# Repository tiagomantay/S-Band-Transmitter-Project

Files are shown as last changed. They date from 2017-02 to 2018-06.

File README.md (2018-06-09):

# S-Band-Transmitter-Project

The project contains the validation PCBs for each transmitter component, developed with KICAD software.

See the file "S-Band Transmitter.pdf" for full documentation.

What are on this repository:

+ KICAD PCBs layouts and schematics

+ 3D preview of each PCB (3D folder)

+ GERBER files

+ Full documentation with simulations and calculations

+ Low cost project with COTS(Commercial off-the-shelf) components

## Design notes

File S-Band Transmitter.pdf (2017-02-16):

UNIVERSIDADE FEDERAL DE SANTA MARIA CENTRO DE TECNOLOGIA
CURSO DE ENGENHARIA DE COMPUTAÇÃO

PROJETO DE UM TRANSMISSOR HOMÓDINO EM BANDA S PARA APLICAÇÕES EM NANOSSATÉLITES

TRABALHO DE GRADUAÇÃO

Tiago Mantay

Santa Maria, RS, Brasil

2016

## PROJETO DE UM TRANSMISSOR HOMÓDINO EM BANDA S PARA APLICAÇÕES EM NANOSSATÉLITES

Tiago Mantay

### Trabalho de Graduação apresentado ao Curso de Engenharia da Computação da Universidade Federal de Santa Maria (UFSM, RS), como requisito parcial para a obtenção do grau de

Bacharel em Engenheiro de Computação

Orientador: Prof. Dr. Renato Machado

Santa Maria, RS, Brasil

2016

Universidade Federal de Santa Maria Centro de Tecnologia
Curso de Engenharia Elétrica

A Comissão Examinadora, abaixo assinada, aprova o Trabalho de Conclusão de Curso

## PROJETO DE UM TRANSMISSOR HOMÓDINO EM BANDA S PARA APLICAÇÕES EM NANOSSATÉLITES

### elaborado por

Tiago Mantay

### Como requisito parcial para a obtenção do grau de

Bacharel em Engenharia Elétrica

COMISSÃO EXAMINADORA:

______________________________ Renato Machado, Dr.
(Orientador)

________________________________ Prof. Marcelo Zanetti, Dr. (UFSM)

___________________________________ Vinícius Ludwig Barbosa, Eng. (UFSM)

Santa Maria, 16 de dezembro de 2016

AGRADECIMENTOS

Agradeço primeiramente a minha família, especialmente meus pais, Elmar e

Juraci, e minha namorada Katiane, que sempre me apoiaram em todos os momentos

pacientemente.

Gostaria de agradecer aos colegas do grupo de pesquisa e amigos Cristiano Santos,

Juliano Rafael Andrade e Vinícius Barbosa pelos momentos compartilhados e troca de

experiências, colaborando de diversas formas.

Agradeço especialmente ao meu orientador, Renato Machado, pela confiança

depositada aceitando a orientação deste trabalho e por toda ajuda e conhecimentos

repassados.

RESUMO

Trabalho de Conclusão de Graduação

Curso de Engenharia de Computação

Universidade Federal de Santa Maria

PROJETO DE TRANSMISSOR HOMÓDINO EM BANDA S PARA APLICAÇÕES EM NANOSSATÉLITES

AUTOR: TIAGO MANTAY

ORIENTADOR: RENATO MACHADO

Local de Defesa e Data: Santa Maria, 16 de Dezembro de 2016

Atualmente, o estudo das tecnologias voltadas para aplicações espaciais tem

crescido consideravelmente. Este fato se deve a redução da complexidade, dos custos e

do tempo envolvido no desenvolvimento de projetos. Satélites de pequeno porte vêm

sendo utilizados para a validação de experimentos científicos e tecnológicos. O sistema

de comunicação é um dos mais críticos componentes de um nanossatélite. Este trabalho

apresenta um protótipo de um front-end de transmissor Homódino de dois canais que

opera em banda S, com componentes comercializados irrestritamente. Por fim, foram

desenvolvidas placas de circuito impresso para validação individual dos componentes que

juntas formam um canal completo do transmissor.

ABSTRACT

Undergradute Final Work

Graduation on Computing Engineer

Federal University of Santa Maria

Technology Center

DESIGNING OF A S-BAND HOMODINE TRANSMITER FOR

NANO-SATELLITES APPLICATIONS

AUTHOR: TIAGO MANTAY

ADVISOR: RENATO MACHADO
Place and Data of Presentation: Santa Maria, December 15th, 2016

Recently, the study of technologies for space applications has grown considerably.

This is due to the reduction of the complexity, the costs and the time involved in the

development of projects. The applicability of small satellites has increased a lot lately,

comes to simplify the validation of scientific and technological experiments. The

communication system is one of the main components of a nanosatellite. This work

presents a prototype of a two-channel Homodine transmitter front-end wich operate in S-

band, with unrestricted commercially available components. Printed circuit boards were

developed for individual component validation, together form a complete transmitter

channel.

LISTA DE ABREVITATURAS E SIGLAS

AEB – Agência Espacial Brasileira

BER – Bit Error Rate (Taxa de erro de bit)

BPSK – Binary Phase Shift Keying (Modulação por Chaveamento de Fase)

CI – Circuito Integrado

FPGA – Field Programmable Gate Array

IF – Frequência Intermediária

INPE - Instituto Nacional de Pesquisas Espaciais

ITA – Instituto Tecnológico de Aeronáutica LEO – Low Earth Orbit (Órbita Terrestre Baixa)

LO – Local Oscilator (Oscilador Local)

MCT – Ministério da Ciência e Tecnologia

PA – Power Amplifier (Amplificador de Potência)

PCI – Placa de Circuito Impresso

RF – Rádiofrequência

SNR – Razão sinal-ruído

VCO – Voltage Control Oscilator (Oscilador controlado por tensão)

UFSM – Universidade Federal de Santa Maria

UFRGS – Universidade Federal do Rio Grande do Sul

LISTA DE FIGURAS

LISTA DE TABELAS

Tabela 6.2: Parâmetros iniciais servindo de base para a escolha dos componentes ....... 37

Tabela 6.5: Representação dos valores de ganhos e figura de ruído em valores lineares e

SUMÁRIO

### 1. INTRODUÇÃO

O setor aeroespacial vem recebendo grandes investimentos por parte do governo

brasileiro, priorizando projetos de pesquisa e desenvolvimento tecnológico que vêm

sendo desenvolvidos pela academia, institutos de pesquisa e através da parceria entre

estes. Uma das áreas considerada como estratégica e prioritária para o governo brasileiro

é a área de satélites, a qual é imprescindível para diversos segmentos como o de

monitoramento ambiental, telecomunicações e defesa.

A academia tem desenvolvido diversos trabalhos envolvendo nanossatélites, os

quais são uma boa opção para a realização de testes e validação de conceitos por

oferecerem menor custo e complexidade do que os satélites de maior porte. Em geral,

podem ser projetados para realizar missões para telemetria de dados coletados por

dispositivos como sensores de temperatura, magnetômetro, entre outras aplicações.

Cientes do potencial estratégico, o Instituto Nacional de Pesquisas Espaciais (INPE) em

parceria com a Agência Espacial Brasileira (AEB) vêm desenvolvendo programas para

construção de satélites de pequeno porte no Brasil desde 2003.

A comunicação do satélite com as estações terrenas é viabilizada pelo subsistema

de telemetria e telecomando, responsável por enviar dados da carga útil e dos sistemas de

bordo e receber comandos. Na maioria dos projetos nacionais de satélites de pequeno

porte foram utilizados transceptores de empresas estrangeiras, adicionando custos

consideráveis ao projeto.

### 1.1 Objetivos

O objetivo deste trabalho é desenvolver um protótipo de front-end de transmissor

que possa ser utilizado em nanossatélites. Mais precisamente, o trabalho propõe um

protótipo de baixo custo de um circuito transmissor que opere em banda S, com

arquitetura própria, utilizando componentes Off-The-Shelf, para aplicações em

nanossatélites que operam em órbita baixa.

O desafio do projeto está em garantir que o transmissor seja robusto e confiável e

que o receptor detecte e decodifique o sinal de telemetria recebido. As características de um link espacial aumentam a complexidade dos problemas, pois uma vez que o satélite é

lançado não há como realizar modificações ou manutenções. O canal de comunicação

também é um desafio a ser considerado, pois além de distância de transmissão (maior do

que 600km), existem diversas variáveis que podem corromper a informação.

### 1.2 Organização do trabalho

O trabalho incialmente apresenta um breve histórico dos nanossatélites e uma

revisão bibliográfica sobre características da comunicação digital, do canal de

comunicação e eletrônica de alta frequência. A revisão também inclui um estudo sobre a

arquitetura homódina e aspectos relevantes sobre circuitos transmissores.

No Capítulo 3, apresenta-se o projeto do transmissor, que enfatiza a arquitetura e

os componentes utilizados no projeto, as justificativas para as escolhas de padrões

utilizados, além de cálculos necessários para o funcionamento do circuito. Nos Capítulos

4 e 5, discutem-se os layouts das placas para os componentes do circuito e também uma

simulação do desvanecimento do sinal no canal de comunicação.

Por fim, o Capítulo 7, a conclusão, discute as metodologias utilizadas, as

atividades realizadas, as melhorias que poderão ser implementadas em trabalhos futuros

e a aplicação deste trabalho no contexto de nanossatélites.

### 2. NANO-SATÉLITES

Nano-satélites são satélites artificiais miniaturizados, que pesam entre 1 e 10 Kg

e projetados para aplicações em órbita baixa (LEO – Low Earth Orbit). Tipicamente, possuem dimensões de 10 cm³
. Em seu design, na maioria dos casos, são utilizados

componentes off-the-shelf e possuem custo muito inferior a satélites de médio e grande

porte.

O Cubesat, modelo extensivamente utilizado de nanossatélite, é originário de

pesquisadores das Universidades Estadual Politécnica da Califórnia (Cal Poly) e

Stanford, que por volta dos anos 2000 desenvolveram o padrão, juntamente com

especificações necessárias para promover projetos nesse âmbito. Os Cubesats podem

pesar até 1,33Kg

Até 2013, os nanossatélites lançados eram majoritariamente universitários. A

partir daí, pode-se observar um aumento significativo de projetos comerciais e amadores.

A Figura 2.1 apresenta uma ilustração de uma constelação de nanossatélites em órbita

terrestre (THE CUBESAT PROGRAM, 2014).

Figura 2.1 - Ilustração de uma constelação de nanossatélites em órbita terrestre.

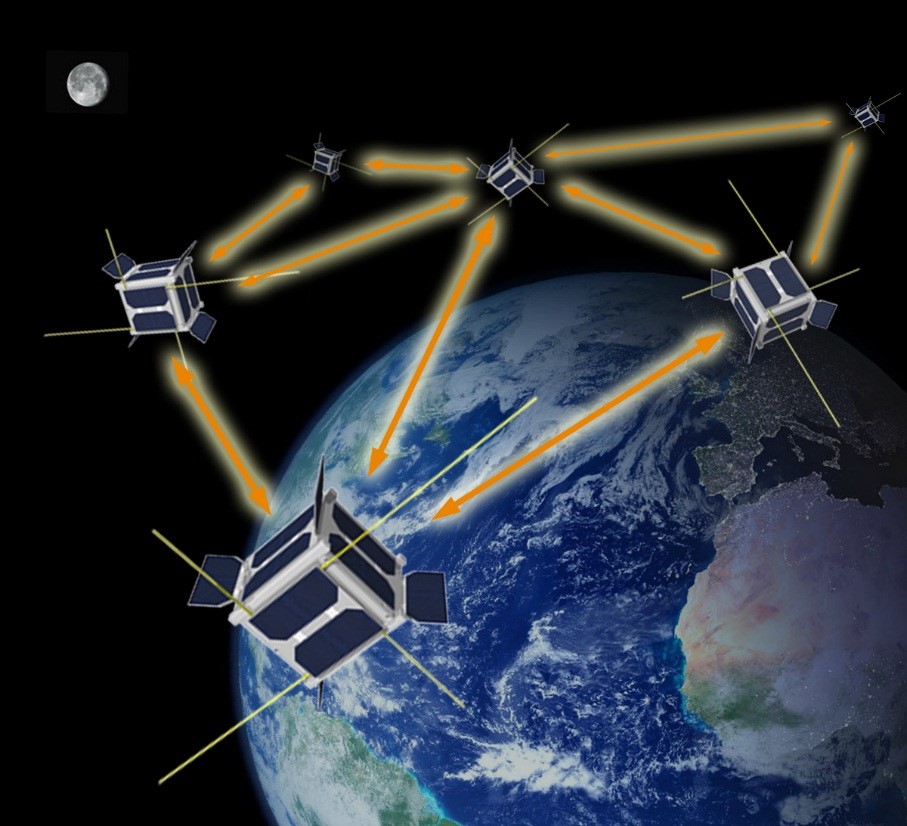
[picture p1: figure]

Fonte: (BENTUM, 2014)

### 2.1 Introdução

Graças aos recentes avanços tecnológicos e do conhecimento acumulado pela

comunidade científica, o número de nano-satélites lançados ao espaço tem aumentado

significativamente. Além disso, o custo de lançamento do satélite, que representa grande

parte do investimento do projeto, tem caído gradualmente à medida que novos lançadores

são construídos e novas tecnologias são empregadas.

As vantagens oferecidas quando em comparação com satélites maiores são muito

expressivas, permitindo que projetos de nível universitário, sem grandes investimentos,

sejam executados com sucesso. Atualmente é possível desenvolver um satélite de

pequeno porte exclusivamente com componentes comerciais do tipo off-shelf.

Além de possuírem a capacidade de realizar tarefas que alguns anos atrás eram

exclusivas de satélites de grande porte, o uso de nanossatélites tem facilitado muito a

realização de todo tipo de experimentos científicos no ambiente espacial. No entanto,

cabe ressaltar que o tempo de vida médio de um nanossatélite em órbita é de 2 anos.

Um sistema de comunicação via satélite necessita no mínimo de um satélite

transmissor e uma estação rádio base para receber as informações do espaço. Para que

haja confiabilidade no tráfego dos sinais, faz-se necessário a implementação de um

protocolo robusto. Esse trabalho avalia dois protocolos clássicos e elege um deles para

conceber o transmissor do projeto. Maiores detalhes são apresentados no Capítulo 3.

A estrutura mecânica utilizada em satélites de pequeno porte é modular, deste

modo a integração dos sistemas é facilitada (BENTUM, 2014).

A Figura 2.2 apresenta um modelo de estrutura mecânica dos Cubesats.

Figura 2.2 – Estruturas padronizadas de Cubesats

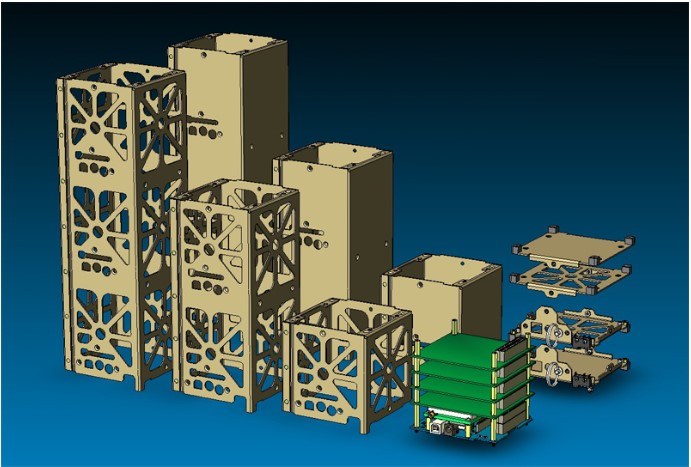
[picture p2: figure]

Fonte: (Clyde-Space, 2009). A ilustração apresenta 3 diferentes modelos de Cubesats. Da esquerda para a

direita, padrão 3U, 2U e 1U.

### 2.2 Missões brasileiras de satélites de pequeno porte

2.2.1 AESP-14

O AESP-14 foi um Cubesat U1, lançado em fevereiro de 2015, declarado

inoperante dias após seu lançamento. Seu objetivo era realizar um estudo da dinâmica da

Atmosfera ionizada. Este projeto foi executado por estudantes de Graduação do ITA e

de Pós-Graduação INPE que fizeram um trabalho de engenharia reversa do satélite

NANOSATC-BR1. O projeto foi executado em Campos do Jordão - São Paulo.

O Cubesat AESP-14 pode ser visto na Figura 2.3 e na Figura 2.4 o transmissor do

desenvolvido no projeto por alunos do ITA e do INPE (INPE, 2015).

Figura 2.3 – Nano satélite AESP-14

Fonte: (INPE, 2015)

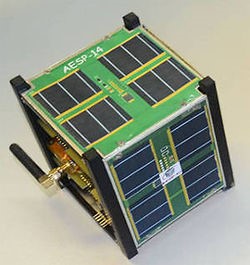
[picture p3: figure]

Figura 2.4 – Transmissor do nano satélite AESP-14

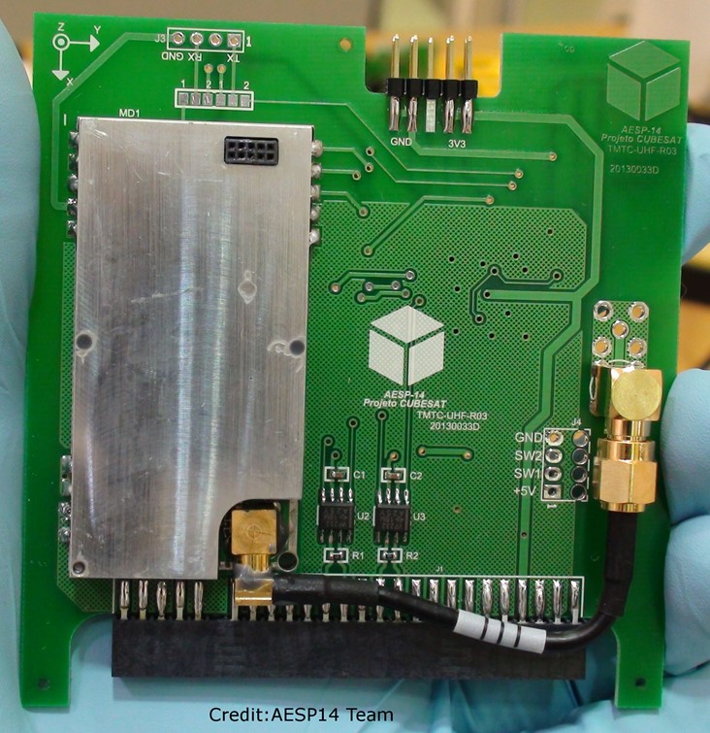
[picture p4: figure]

Fonte: (INPE, 2015)

### 2.2.2 BR-1

Lançado em 19 de julho de 2014, o Cubesat BR-1 foi desenvolvido por

pesquisadores do INPE e da UFSM com dois objetivos, um cientifico e outro tecnológico.

A Missão Tecnológica do NANOSATC-BR1 foi a realização de testes de CIs

tolerantes à radiação ionizante, produzidos por pesquisadores da SMDH em parceria com

a UFSM. A missão científica foi, principalmente, a coleta de dados referentes ao Campo

Magnético Terrestre, na região da América do Sul onde há anomalias no campo

magnético da terra (INPE, 2014).

Segundo Otávio Durão, coordenador de engenharia e tecnologia espacial de

projetos de nanossatélites do INPE, o custo total do projeto foi próximo de R$ 800 mil.

Em 24 de junho de 2014, 5 dias após seu lançamento, as estações terrenas do INPE

em Santa Maria e São José dos Campos, captaram sinais enviados do Cubesat,

comprovando o sucesso do projeto (AEB, 2015). A Figura 2.5 apresenta o Cubesat BR1.

Figura 2.5 – Nano-Satélite BR1. Detalhes da bancada de teste e da carga útil lançada na missão.

Fonte: (INPE, 2015)

### 3. SISTEMAS DE COMUNICAÇÃO DIGITAL

Os princípios da comunicação digital remetem a Claude Shannon, em seu famoso

livro intitulado A mathematical theory of communication (A teoria matemática da

comunicação), publicado em 1949 em coautoria com Warren Weaver. Neste livro,

lançado após o artigo de mesmo nome, são sistematizados conceitos fundamentais para o

entendimento da eficiência em sistemas de comunicação que possibilitaram grandes

avanços na área (KINCHIN, 1957).

Um sistema de comunicação tem como propósito transportar uma mensagem de

um ponto no espaço a outro. Se o sistema for digital, a mensagem será composta de dados

(bits). Os principais componentes de um sistema de comunicação são: a fonte de

informação, o transmissor, o receptor e o destino (LATHI, 1998).

O diagrama da Figura 3.1 apresenta os componentes de um sistema de

comunicação digital.

Figura 3.1 – Diagrama de um sistema de transmissão de dados

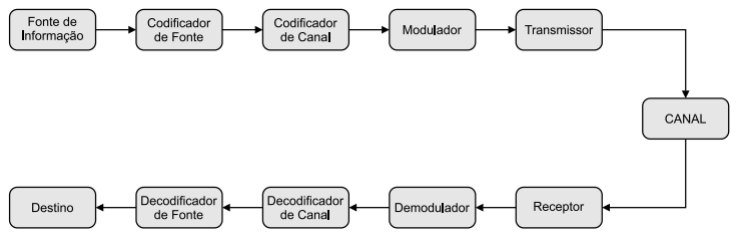
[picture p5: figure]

Fonte: (Autoria própria)

- Fonte de Informação – onde a informação é gerada
- Codificador de Fonte – retira o excesso de redundância proveniente da

fonte de informação;

- Codificador de Canal – responsável por codificar os sinais de informação

objetivando a redução da BER durante a transmissão;

- Modulador – realiza o processo de conversão digital/analógico, necessário

para inserir informações em um sinal analógico;

- Transmissor – componente responsável pela manipulação e o envio do

sinal através do canal;

- Canal – meio físico por onde o sinal é propagado, adicionando sempre

ruídos ao sinal original;

- Receptor – componente responsável por receber e tratar o sinal que se

propagou através do canal;

Receptores, transmissores e transceptores, geralmente são responsáveis por

acumular outras funções como modulação/demodulação, codificação/decodificação,

amplificação, filtragem, verificação de erros, entre outros procedimentos (LATHI, 1998).

### 3.1 Transmissão de dados

Os sistemas de comunicação podem operar de diferentes formas e empregar

diferentes técnicas. Basicamente, pode-se classificar um sistema de comunicação

considerando o fluxo de informações do transmissor para o receptor. Os esquemas de

transmissão podem ser classificados de acordo com a habilidade dos agentes transmitirem

e receberem informações ao longo do tempo, dessa forma existem três modalidades:

Simplex, Half-duplex e Full-duplex.

3.1.1 Transmissão Simplex

Este esquema é caracterizado pela existência de um agente transmissor e um

agente receptor. O modelo Simplex é largamente empregado por estações de rádio,

sistema GPS e satélites.

3.1.2 Transmissão Half-Duplex

O esquema Half-duplex permite que ambos agentes transmitam e recebam

informações, porém somente um agente pode transmitir por vez. Rádios amadores

utilizam o esquema Half-duplex para comunicarem entre si.

3.1.3 Transmissão Full-duplex

Sistemas de comunicação onde ambos agentes podem enviar e receber dados

simultaneamente são chamados de Full-duplex. A telefonia é um exemplo de esquema

Full-duplex, onde os dois agentes de comunicação podem receber e enviar dados

simultaneamente (LATHI, 1998).

A Figura 3.2 apresenta uma ilustração dos esquemas Simplex, Half-duplex e Full-

duplex.

Figura 3.2: Esquemas de transmissão

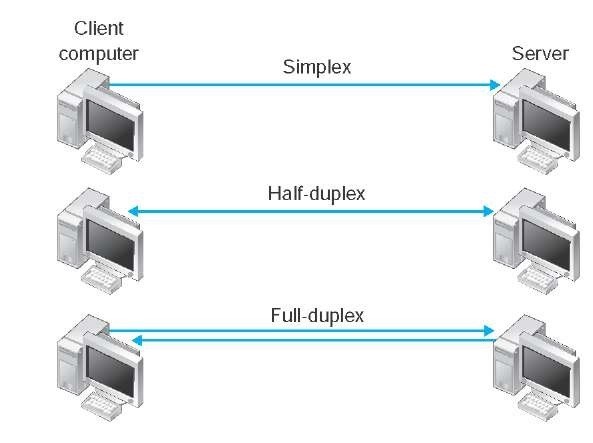
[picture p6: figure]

Fonte: (Autoria própria). Modelo de esquemas de transmissão.

### 3.2 Características de um sistema de comunicação wireless

Existem sistemas de comunicação de todos os níveis, local, regional, nacional e

global. Cada sistema deve possuir as características que a sua aplicação demande. A

distância de transmissão, a qualidade, a confiabilidade e a velocidade dos dados são

fatores de extrema importância na construção de um sistema de comunicação.

O conhecimento dos efeitos gerados pelo canal de comunicação utilizado pelo

sistema é de vital importância no projeto. O ruído acrescentado pelo canal tem grande

influência na arquitetura e nas tecnologias empregadas no sistema de comunicação, para que o mesmo seja eficiente e confiável. Atualmente a transmissão sem fio (wireless) é

largamente utilizada pelas facilidades oferecidas, porém, a vantagem de não necessitar

meios físicos artificiais traz como desvantagem a enorme quantidade de efeitos

indesejados ao sinal transmitido.

De forma geral, as características mais importantes que definem um sistema de

comunicação sem fio são a taxa de dados, a largura de banda, a frequência de transmissão

e a SNR desejada (RAPPAPORT, 2011).

3.2.1 Taxa de dados

Uma das características mais importantes em um sistema de comunicação é a

velocidade de transmissão, ou seja, a quantidade de dados enviados por unidade de tempo.

Essa medida pode ser chamada de taxa de dados ou bit rate, e é usualmente expressa em

bits por segundo ou símbolos por segundo.
É apropriado definir, nas primeiras etapas do projeto, a taxa de dados mínima

requerida, para então dimensionar e definir as demais características do sistema.

Geralmente deseja-se a maior taxa de transmissão possível dentro dos limites de execução

do projeto.

A velocidade da transmissão está intimamente associada a outros fatores como a

qualidade da transmissão, a modulação empregada, a redundância e, principalmente, o canal de comunicação. É necessário garantir baixos índices de BER, e a maior SNR

possível no receptor, para evitar retransmissões de dados.

3.2.2 Largura de banda

A largura de banda de um sistema é a faixa de frequência que será utilizada para

o envio das informações. Este parâmetro tem relação direta com a capacidade de

transmissão. Para um canal ideal (sem adição de ruído), quanto maior a largura de banda,

maior será a capacidade do canal, segundo a Equação 3.1.

C = 2B | (3.1)

Em que C é a capacidade do canal e B a largura de banda do sinal (Hz) no caso do

sistema utilizar 2 níveis de tensão, ou seja, 1 símbolo por bit (NASCIMENTO, 2007).

A Equação que apresenta a capacidade do canal para sinais com N níveis, é

apresentada a seguir:

C = 2B log2 N | (3.2)

3.2.3 SNR

A relação sinal-ruído estabelece uma importante relação entre a potência do sinal

e a potência do ruído no receptor. Esta relação é logarítmica e expressa em dB pela

Equação abaixo.

S
N

= 10 log potência do sinal potência de ruído

(3.3)

Quanto menor a diferença entre as potências do sinal transmitido e do ruído, maior

será a probabilidade que ocorra um erro de bit. De modo que a potência do sinal recebido

deve ser suficientemente maior que a potência de ruído para que seja possível decodificar

a informação.

3.2.4 Erro de bit

A taxa de erro de bit ou BER (Bit Error Rate) é a relação direta entre a quantidade

de bits transmitidos e a quantidade de bits decodificados erroneamente e constitui um

parâmetro fundamental para avaliar-se a qualidade de transmissão. Quanto maior a BER

de um sistema, menor será a taxa efetiva de transmissão de bits, pois mais bits terão de

ser retransmitidos ou serão perdidos.

3.2.5 Frequência de transmissão

Em sistemas de transmissão sem fio, surge a necessidade de utilizar uma

frequência, denominada portadora, que utilizada para “carregar” a informação

transportada pelo canal. O espectro de frequências utilizado deve estar em conformidade

com a legislação (no Brasil regida pela ANATEL). Além disso, a portadora terá grande influência sobre o projeto do sistema de comunicação no que se refere ao efeito do canal,

projeto das antenas e do receptor/transmissor.

A frequência portadora modula o sinal através do processo chamado

upconversion, e será recuperado no receptor através do processo de downconversion

(NASCIMENTO, 2007).

Este processo é resultado da operação chamada de convolução dos dois sinais,

conforme ilustra a Figura 3.3.

Figura 3.3 – Processo de upconversion

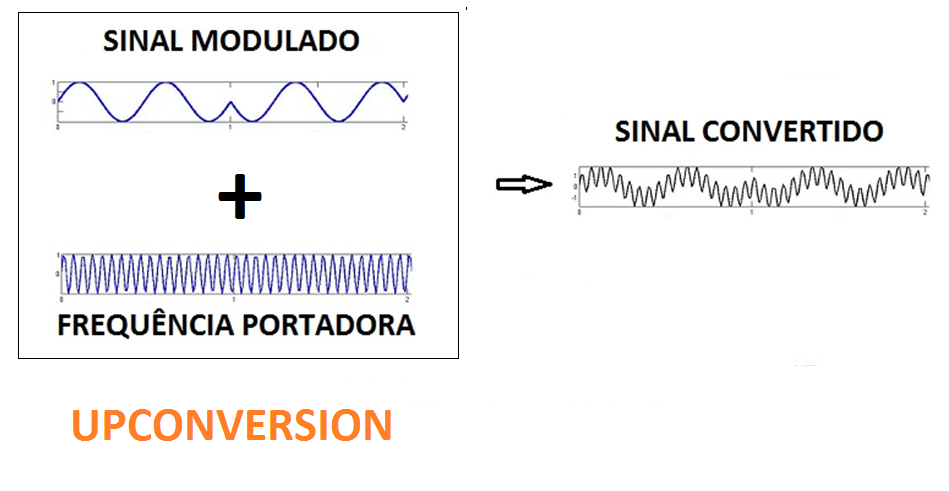
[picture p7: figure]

Fonte: (Autoria própria). Processo de conversão de um sinal modulado para a frequência de transmissão,

no processo chamado upconversion.

### 3.3 O canal de comunicação

Existem diversos meios físicos para conduzir o fluxo de informações do

transmissor até o receptor, guiados ou não-guiados. Esses meios são chamados de canais

de comunicação. O sinal pode trafegar por meio de condutores sólidos, líquidos ou

gasosos. Os meios mais utilizados atualmente são sólidos (cabos) e gasosos (ar).

Para transmissões sem fio, o canal de comunicação é um dos primeiros fatores

limitantes a ser levado em consideração quando se está projetando sistemas de

comunicação pelo fato de, geralmente, causarem maior parte das atenuações e

interferências no sinal em questão. (TANENBAUM, 1996)

3.3.1 Modelagem do canal de Comunicação

A Equação de Friis simplificada, (Equação 3.4) nos permite realizar uma

aproximação do cálculo da perda de potência no espaço livre, utilizando como parâmetros

os ganhos das antenas, a potência de transmissão, a distância entre transmissor e receptor

e comprimento de onda do sinal (LATHI, 1998).

Pr = Pt ∗ (

λ
4πd)

2
∗ Gt ∗ Gr | (3.4)

Sendo :

Pr a Potência recebida em watts
Pt a Potência transmitida em watts λ o Comprimento de onda em metros Gt o Ganho da antena transmissora Gr o Ganho da antena receptora

O comprimento de onda (λ) pode ser calculado a partir da frequência (F), em que v = 300.000.000 m/s. (RAPPAPORT, 2011)

λ =

v
F

(3.5)

### 3.4 Modulação digital

A modulação é o processo que permite adicionar informação a um sinal através

da variação de frequência (FM), amplitude (AM) ou fase (PM) do sinal. Esse processo

pode ser executado na forma analógica ou digital.

O circuito analógico requer o projeto individual para cada tipo de modulador, ou

seja, diferentes componentes deverão ser especificados para que o circuito atenda a

demanda requisitada. Por outro lado, a modulação digital é muito mais versátil,

permitindo a programação e implementação de diversos esquemas de modulação com o

mesmo circuito físico. Para fins práticos, independentemente do processo de modulação considerado, o sinal resultante desse processo é analógico (HAYKIN, 2004).

3.4.1 BPSK

A modulação BPSK (do inglês, Binary Phase Shift Keying) é uma modulação que

emprega o sistema de deslocamento de fase e possui a capacidade de transmitir 1 bit por

símbolo. Sendo considerado um esquema robusto, além de facilitar o tratamento de erros.

Além de ser um esquema muito robusto, ou seja, tolerante a um nível alto de ruído,

o esquema BPSK também é de fácil implementação (RAPPAPORT, 2011).

### 3.5 Protocolos de comunicação

Para garantir a funcionalidade e eficiência no processo de comunicação é

necessário a definir qual padrão será utilizado para transmissão/recepção do sinal. Os

protocolos devem ser escolhidos de forma que o formato dos dados facilite a

implementação das diversas funcionalidades do sistema.

Quando se transmite dados digitais, estes devem seguir uma métrica, devem ser

divididos e quantificados. A divisão dos dados é implementada através de pacotes. Cada

pacote carrega, além dos bits de dados a serem enviados, bits de controle para detecção e

correção de erros, bits de endereçamento, entre outras funções. Há protocolos que são

mais utilizados que outros, normalmente por terem sido mais testados e aperfeiçoados ao

longo do tempo.

Em aplicações militares ou que requeiram um nível maior de segurança ou

customização, pode vir a ser necessário implementar um protocolo próprio para o sistema

idealizado. (LATHI, 1998)

3.5.1 Modelo OSI

O modelo OSI (Interconexão de Sistemas Abertos, do inglês: Open Systems

Interconnection) foi desenvolvido a fim de criar um padrão de protocolo de comunicação

entre sistemas, garantindo a compatibilidade em redes de dados digitais. Ao total são 7

camadas: Física, enlace, rede, transporte, sessão, apresentação e aplicação. Em muitos

sistemas não há necessidade de implementação de todas as camadas do modelo OSI

(TANENBAUM, 1996).

A Figura 3.4 descreve as camadas da estrutura do modelo OSI

Figura 3.4: Camadas do modelo OSI

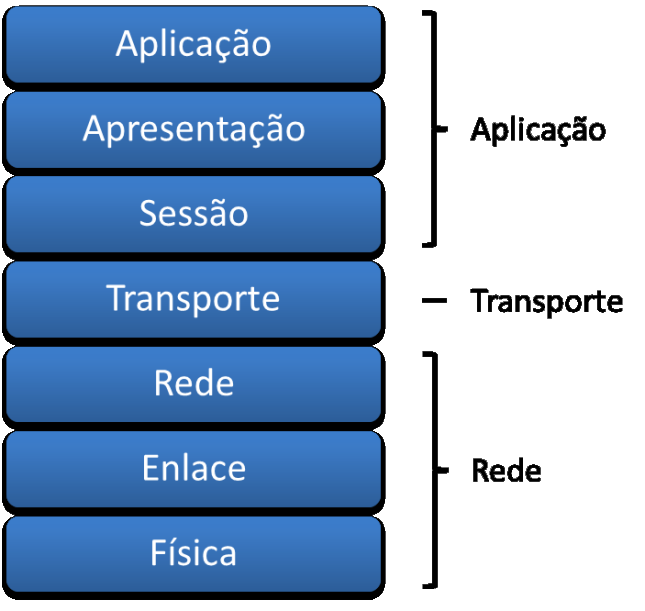
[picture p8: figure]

,

Fonte: (Autoria própria)

3.5.2 Protocolo AX.25

O objetivo deste protocolo é assegurar a compatibilidade entre estações de

transmissão e recepção, permitindo a usuários um alto nível de integração entre as partes

de um sistema de comunicação. Um padrão amplamente utilizado traz consigo muitos

benefícios, principalmente pelo fato de ser continuamente testado e melhorado.

O AX.25 foi derivado do protocolo X.25 e foi desenvolvido por operadores de

radioamador. Os avanços no protocolo X.25 foram necessários para permitir a inclusão

das opções de endereçamento e outras características da transmissão via rádio.

A ampla compatibilidade do AX.25 com milhares de rádio amadores do mundo

inteiro é um dos motivos que justificam a aderência por diversos projetistas, incluindo

nano satélites. O diagrama das camadas OSI do protocolo AX.25 pode ser visualizado na

Figura 3.5 apresentando uma estrutura com 3 camadas, implementadas na estação de

controle, no satélite e nos terminais (ADDAIM, 2010).

Figura 3.5 – Camadas da comunicação via satélite

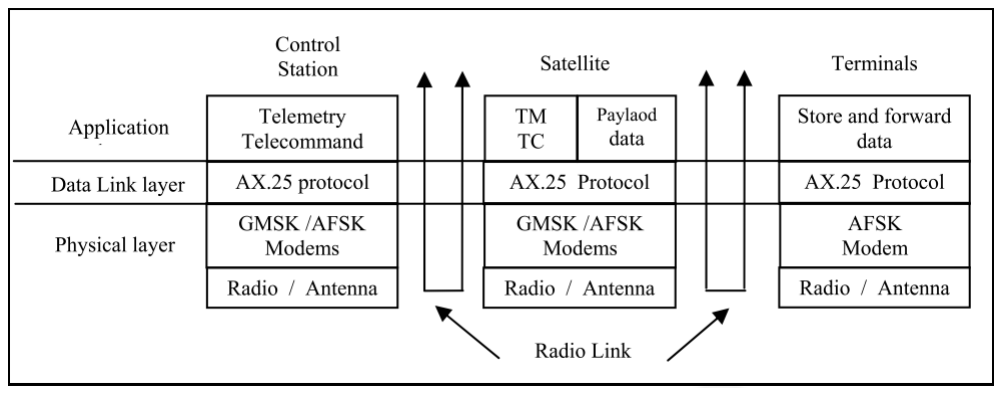
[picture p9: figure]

Fonte: (ADDAIM, 2010)

Este protocolo provê o serviço de padronização das comunicações sem necessitar

camadas superiores do modelo OSI. Além de ser funcional na operação com circuitos de

RF parcialmente prejudicados, o protocolo possui inúmeros benefícios e otimizações que

foram sendo incorporados ao longo dos anos.

O AX.25 oferece uma interface que prevê correções e detecções de erros,

retransmissão de pacotes, opções de controle e possibilidades de encapsulamento via

pacotes IP ou UDP. A Figura 3.6 ilustra um pacote de que segue o protocolo AX.25.

(Tucson Amateur Packet Radio Corporation, 1998).

Figura 3.6: Pacote de informação do protocolo AX.25

Fonte: (Tucson Amateur Packet Radio Corporation, 1998).

Nanossatélites que utilizam o protocolo AX.25 possibilitam que usuários de

radioamador possam receber e decodificar os sinais advindos do espaço, auxiliando os

pesquisadores na confirmação do funcionamento dos dados obtidos pela carga útil dos

satélites.

### 4. LINHAS DE TRANSMISSÃO E MICROONDAS

Em sinais com componentes de alta frequência (microondas), elementos de

circuitos como resistores, capacitores e indutores apresentam um comportamento muito

diferente de quando se trabalha com baixas frequências. Este fenômeno ocorre porque

existe, para altas frequências, uma maior expressão do efeito skin e das perdas por

radiação nesses componentes e nas PCIs.

Para sinais com frequências superiores a 300 MHz, o comprimento de onda do

sinal passa a ser suficientemente pequeno (aproximadamente 1 metro) para que haja

variações na fase da tensão e da corrente no circuito. Deste modo as teorias de circuito,

conhecidas como as Leis de Kirchoff, não podem ser empregadas, pois os valores de

tensão e corrente não são mais constantes. Logo, para circuitos de RF emprega-se o estudo

das linhas de transmissão.

Uma linha de transmissão é um disposto condutor elétrico responsável por

transportar um sinal de RF entre dois pontos (RAZAVI, 2011).

### 4.1 Distorção Harmônica

Se um sinal senoidal é aplicado a um sistema não-linear, a saída deste sistema irá

ser composta, além do sinal de entrada, de componentes em frequência que são múltiplos

inteiros deste sinal, chamados de harmônicos.

Dado um sinal, x(t) = Acos (ω ft), onde ω = 2πf, onde o mesmo é aplicado na

entrada do sistema que possui a função de transferência estabelecida pela Equação 4.1, a

resposta do sistema será descrito como na Equação 4.2 e 4.3.

y(t) = a1x(t) + a2x

2
(t) + a3x

3
(t) + ⋯ + anx
n(t) | (4.1)

y(t) = α1Acos(ωt) + α2A

2

cos²
(ωt) + α3A

3

cos³
(ωt) + ⋯ (4.2)

=

α2A

2

2

+ (α1A +

3α3A

3

4

) cos(ωt) +

α2A

2

2

cos(2ωt) +

α3A

3

4

cos(3ωt) … (4.3)

As componentes indesejadas do sinal, se somam ao sinal, porém multiplicadas

pelo termo da amplitude ao cubo, de forma que podem ser mais expressivas que o próprio

sinal original.

### 4.2 Parâmetros S

Os parâmetros S dos componentes de RF fornecem todas as informações

necessárias para calcular as variáveis da rede como o ganho e o coeficiente de reflexão.

Por fornecerem simplicidade com uma boa precisão na determinação dos parâmetros

através dos coeficientes da matriz S, são amplamente preferidos quando se trabalha com

baixas amplitudes de sinal.

Um dispositivo de duas portas geralmente é descrito por tensões e correntes

externas de cada porta ou por ondas de tensão incidentes (parâmetros S – Scattering

parameters). Sendo N o número de portas, os coeficientes de espalhamento da matriz S serão da ordem de N²

As Equações 4.4, 4.5 e 4.6 relacionam as variáveis de corrente de entrada de

corrente de saída e impedância do circuito, são dadas, respectivamente, por

(NASCIMENTO, 1992)

I1 = S11 ∗ V1 + S12 ∗ V2 | (4.4)
I2 = S21 ∗ V1 + S22 ∗ V2 | (4.5)

Z1 =

V1 I1
e Z2 =
V2 I2 | (4.6)

Os parâmetros S do circuito podem ser calculados por

S11 =

I1
V1
, para curto circuito na saída (V2 = 0). | (4.7)

S22 =

I2
V2
, para entrada com impedância casada (V1 = 0). | (4.8)

S21 =

I2
V1
, para saída com impedância casada. (V2 = 0). | (4.9)

S12 =

I1
V2
, para curto circuito na saída (V1 = 0). | (4.10)

### 4.3 Cálculo da figura de ruído

Todos os componentes de um circuito que opere em alta frequência apresentam

um ruído associado a uma fonte térmica. Este ruído pode ser modelado como uma

resistência que varia com a temperatura. A potência de ruído térmico é apresentada por

(POZAR, 2005):

NO = GkTkB | (4.11)

Sendo:

G o ganho do dispositivo

B a largura de banda

k a constante de Boltzmann (1,38 x 10⁻²³

J
K

⁄ )

O primeiro estágio do circuito tem grande impacto no desempenho total, pois o

termo (G1) é multiplicado no divisor de todas as parcelas seguintes. Quanto maior a

quantidade de parcelas, maior será a influência dos primeiros elementos na figura de ruído

do sistema.

O cálculo da figura de ruído de um circuito é calculado da seguinte forma

### NF = NF1 +

NF2−1
G1

+

NF3−1
G1⋅G2

+

NF4−1
G1⋅G2⋅G3

+

NF5−1
G1⋅G2⋅G3⋅G4
+ ⋯ | (4.11)

Sendo:

F a figura de ruído do dispositivo

G o ganho do dispositivo (em dB)

NF a figura de ruído total do sistema

### 5. CIRCUITOS TRANSMISSORES

Há três principais métodos conhecidos para implementação de um front-end de

transmissor RF, que são:

I. Design de um transmissor encapsulado em um microchip, através de

técnicas de circuitos integrados;

II. | Fabricação de um circuito eletrônico com componentes discretos e
| interligados através de uma Placa de Circuito Impresso (PCI);
III. | Utilização de uma FPGA para implementação de algoritmos
| (programados) e circuitos analógicos auxiliares.

O primeiro método possui um alto nível de complexidade, exige tempo de projeto

e custo de implementação expressivo e profundos conhecimentos em concepção de CIs,

em contrapartida pode oferecer uma solução mais eficiente e com menores dimensões

físicas. A terceira opção possui vantagens como a possibilidade de reconfiguração do

circuito físico remotamente, porém necessita de circuitos auxiliares que devem ser

corretamente integrados, além do alto consumo de energia.

No presente trabalho, o projeto do front-end será desenvolvido com o segundo

método, utilizando componentes eletrônicos já existentes no mercado e a prototipação de

placas de circuito impresso para interligação e fixação dos componentes. Este método

requer cálculos e conhecimentos de engenharia de microondas, no entanto o custo de

implementação é mais baixo.

### 5.1 Arquitetura de circuitos transmissores

5.1.1 Arquitetura de conversão direta (homódina)

A partir de um modelo simplificado de um transmissor representado na Figura

5.1, existem duas arquiteturas principais de transmissores digitais de RF: Arquitetura de

Conversão direta ou homódina (Figura 5.2) e de conversão indireta (ou heteródina).

Figura 5.1 - Modelo básico de um transmissor

Fonte: (Razavi, 1998)

As arquiteturas se diferenciam, basicamente, na existência de um ou mais estágios

de conversão do sinal. O circuito Homódino possui somente um estágio de conversão

enquanto que o Heteródino possui dois ou mais estágios. (Razavi, 1998)

Figura 5.2 - Arquitetura de conversão direta (Homódina)

Fonte: (Razavi, 1998)

### 5.2 Componentes de um transmissor

Um transmissor basicamente é um sistema que é capaz de transmitir sinais.

Todavia, para executar tal tarefa, é necessário que o sinal a ser transmitido esteja

condicionado. Desta forma, é necessário realizar a amplificação, a filtragem e o

tratamento da impedância do sinal. Para transmissores com mais de um canal é necessário

também um controle de seleção do canal a ser transmitido e possivelmente a

sincronização entre eles.

5.2.1 Filtros

Componente passivo seletivo em frequência, que atenua uma parte do sinal de

entrada. Os tipos de filtros mais comuns são: Passa-baixa, passa-alta e passa-banda. O funcionamento consiste na atenuação das frequências indesejadas, através da inserção de

ruído, e a capacidade de permitir a passagem do sinal na frequência de interesse

(Razavi, 2011)

5.2.2 Mixer

Realiza a soma ou diferença dos sinais de entrada. Possui 3 portas sendo duas de

entrada e uma de saída, além da alimentação e aterramento. A frequência do sinal de saída

resultante do mixer é:

fIF = f1 ± f2 | (5.1)

IF – Saída – Sinal da portadora modulado

LO – Entrada – Sinal do Oscilador com a frequência portadora

RF – Entrada – Sinal do Modulador com sinal responsável pela modulação

5.2.3 Amplificador

Para que o sinal de RF chegue na antena com potência suficiente, é necessário um

estágio de amplificação. O amplificador basicamente aumenta a potência do sinal de

entrada, aumentando sua amplitude. Entretanto todos amplificadores, como não são

dispositivos ideais, acabam por distorcer no sinal de saída.

A qualidade da amplificação é diretamente proporcional a fidedignidade do sinal

amplificado. Desta forma prioriza-se uma relação entre potência e qualidade condizente

com as especificações do circuito projetado.

5.2.4 Multiplexador

O multiplexador é um dispositivo utilizado para fazer a seleção do canal de saída, através da combinação de bits de controle. Se existirem n entradas, serão necessários 2n

bits de controle para selecionar a saída desejada.

Neste projeto, o transmissor possui 2 canais de entrada. Desta forma o

multiplexador é responsável pela seleção do canal.

### 6. PROJETO DO CIRCUITO TRANSMISSOR

### 6.1 Metodologia do projeto

A metodologia do projeto consiste principalmente em:

- Revisão bibliográfica dos conceitos de comunicação de dados, micro-

ondas, componentes eletrônicos, envolvidos no projeto;

- Estudo de conceitos, aplicações e legislação pertinentes ao projeto no

âmbito de nano satélites;

- Definições de projeto: parâmetros, protocolos, tecnologias e arquiteturas;
- Cálculos e simulações referentes aos diferentes estágios de manipulação

dos sinais;

- Construção de placas para validação dos componentes escolhidos;
- Testes das placas de validação com os componentes reais;
- Desenvolvimento de um canal completo do transmissor;

### 6.2 Considerações iniciais para o projeto

Grande parte dos projetos de nano satélites possui estrutura modular, sendo

possível desenvolvê-lo com ajuda de sistemas eletrônicos especializados vendidos

comercialmente. Como o sistema de comunicação é um dos principais elementos do

projeto, sendo talvez o de maior complexidade, grande parte dos projetistas acabam por

buscar soluções comerciais, que possuem um custo expressivo pelo fato de utilizarem as

mais modernas tecnologias de fabricação e por ser exaustivamente testadas (ADDAIM,

2010).

Devido à complexidade da construção de um transmissor de RF, especialmente

para aplicações espaciais, o presente trabalho tem como intuito produzir um protótipo

funcional de um Circuito Transmissor Homódino.

O desenvolvimento de transmissores nacionais para o ambiente espacial, é de

grande importância para o desenvolvimento tecnológico do Brasil. A independência

tecnológica, no âmbito espacial, é vital para que garantir o pioneirismo e o sucesso de

projetos apoiados pela AEB e MCT (AEB, 2015).

Para contextualização do projeto, foi realizada uma análise de tecnologias de

transmissão empregadas em nanossatélites lançados nos últimos anos. Através da análise

dos dados obtidos da Tabela 6.3 pode-se afirmar que algumas características são comuns

à maioria dos projetos, dessa forma, a Tabela 6.1 apresenta os dados dos padrões e

parâmetros mais utilizados pelos projetos analisados.

Pode-se perceber que a velocidade de transmissão é o parâmetro com a maior

variação entre os considerados. Essa variação ocorre por diversos fatores inerentes ao

comportamento apresentado pelos circuitos, sinais transmitidos e definições de projeto.

Tabela 6.1 – Características genéricas de Cubesats

Frequência de Downlink | ~2,4 Ghz e ~433 Mhz
Taxa de transferência de dados | 1,2 Kbps a 1,5Mbps
Potência de transmissão | 500mW a 2W
Protocolo de comunicação | AX.25

Tabela 6.2: Parâmetros iniciais servindo de base para a escolha dos componentes

Definições iniciais para o projeto
Frequência de transmissão | 2,26 Ghz
Arquitetura do circuito | Homódina
Tipo de encapsulamento dos componentes | SMD
Montagem dos circuitos físicos | PCI
Modulação Digital | BPSK
Protocolo de comunicação | AX.25
Impedância das trilhas e componentes | 50 Ω
Software para simulação dos sinais | Matlab
Software para o layout das PCIs | Kicad

Tabela 6.3 – Transmissores de Cubesats lançados entre 2009 e 2011

Fonte: (MURI, 2012)

### 6.3 Simulação de transmissão - Perdas de transmissão no espaço livre

O objetivo foi simular, com auxílio do software MATLAB®, a potência recebida

por uma antena isotrópica, com a ajuda de cálculos aproximados pela equação de Friis,

através da transmissão em três frequências diferentes (500 MHz, 1 GHz e 3 GHz) e

verificar o efeito da frequência no desvanecimento do sinal e a potência recebida ao longo

de 600 km.

Para realizar o cálculo, foram utilizados valores extraídos do projeto CONASAT

do Instituto Nacional de Pesquisas Espaciais (INPE), em que a potência de transmissão

utilizada foi de 0,5 W e o ganho da antena transmissora 6 dB. Segundo o INPE, a recepção

dos dados pela estação terrena do CRS localizado em Santa Maria é feita através de uma

antena com ganho de 21,4 dB. Desse modo foram utilizados os valores de Gr=6 dB e

Gr=20dB para simulação.

Através da simulação, obteve-se para uma transmissão de 2,26 Ghz com potência de 0,5 W, a potência recebida de aproximadamente 6,20 fW a 600 km de distância. É

perceptível que o desvanecimento é inversamente proporcional a frequência. Os valores

obtidos para 500 Mhz, 1 Ghz e 3 Ghz foram, respectivamente, 1,26 pW, 31,60 fW e 3,52

fW.

O gráfico da Figura 6.1 apresenta a relação de perda em função da distância em

escala semilog e a Figura 6.2, em escala loglog, para linearizar a curva de

desvanecimento.

A fórmula de Friis nos fornece uma aproximação otimista, os dados obtidos

servem como base para cálculo de outros parâmetros nas próximas etapas do projeto.

Figura 6.1 – Gráfico do desvanecimento do sinal

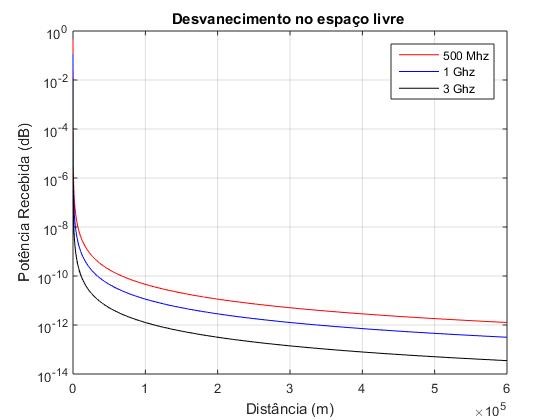
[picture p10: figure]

Fonte: (Autoria própria). Gráfico representando o desvanecimento do sinal ao longo da distância de 600

Km para as frequências de 500 MHz, 1 GHz e 3 GHz (eixo X em dBw e eixo Y representando a distância

em metros).

Figura 6.2 – Gráfico que apresenta a potência do sinal na antena do transmissor

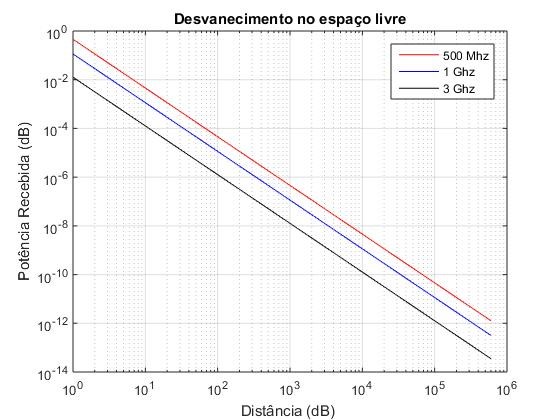
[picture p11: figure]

Fonte: (Autoria própria). Gráfico das três frequências representando A potência recebida pela distância de

600 Km (Eixo X em dBw e eixo Y dB).

### 6.4 Escolha da Arquitetura do circuito

Como o projeto tem como objetivo apresentar um protótipo de um transmissor,

buscou-se optar por elementos de menor complexidade e custo. Essa abordagem é válida,

pois para projetos de alta complexidade deseja-se, incialmente, simplificar e dividir o

problema para atingir um resultado positivo.

Após um estudo realizado sobre as arquiteturas de transmissores optou-se pela

arquitetura homódina devida a baixa complexidade e a menor quantidade de componentes

utilizados.

Foi introduzido um amplificador logo após o Filtro 1, utilizando uma técnica que

permite aumentar significativamente a SNR resultante utilizando um elemento com alto

ganho nos primeiros estágios do circuito (RAZAVI, 2001).

A Figura 6.3 apresenta um front-end de transmissor Homódino de dois canais.

Figura 6.3 – Diagrama do transmissor com dois canais

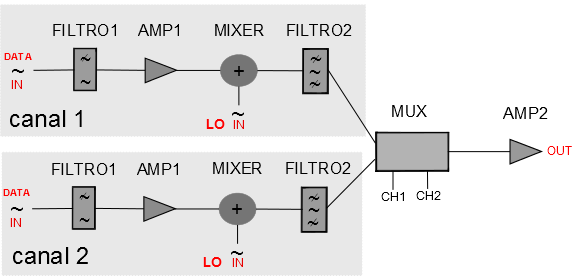
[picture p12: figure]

Fonte: (Autoria própria).

### 6.5 Escolha dos componentes do circuito

Para especificar os componentes, torna-se necessário adquirir informações das

características pelo projeto. A taxa de dados, a distância máxima de transmissão, o

consumo de potência, as dimensões físicas são exemplos dessas características.

A frequência definida para a transmissão neste projeto é 2,26 GHz. Esta

frequência está na faixa denominada UHF, também classificada como Banda S. Este

parâmetro apresenta maior impacto na escolha dos componentes.

Para todos os componentes, priorizou-se os que apresentaram menor adição de

ruído e distorção do sinal, maior ganho, dimensões físicas e encapsulamento apropriadas

e um custo x benefício ótimo. Todos os componentes escolhidos são provenientes da

empresa Minicircuits, sediada nos Estados Unidos, por oferecerem uma vasta gama de

dispositivos com certificações de qualidade comprovadas por diversos projetistas.

Utilizando todos os componentes que compõem um canal completo do

transmissor, o circuito resultante pode ser visualizado na Figura 6.4.

Figura 6.4 – Diagrama de um canal do circuito transmissor

Fonte: (Fonte própria). Diagrama de um canal do circuito transmissor com a ilustração

dos componentes selecionados

Para efeitos de teste, o sinal de entrada do mixer, contendo a portadora com

2,26GHz, pode ser gerado por um gerador de sinais. Pode-se também utilizar um VCO

(Voltage Control Oscilator) para realizar a geração do sinal na frequência de interesse. O

sinal de entrada, conectado a entrada do Filtro 1, também pode ser gerado por um gerador

de sinal. Esse sinal contém a informação modulada a ser transmitida.

### 6.6 Cálculo da potência dos sinais

O componente que limita a potência dos sinais de entrada é o mixer, cada entrada

tem o limite de potência estabelecido pelo fabricante em 17 dBm. A Figura 6.5 apresenta

um diagrama dos sinais na entrada do componente.

Figura 6.5 – Representação dos sinais no diagrama do transmissor

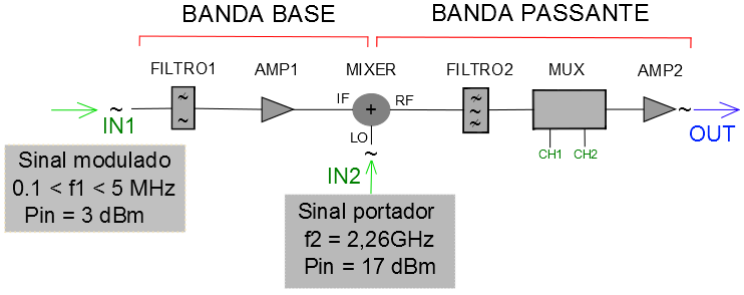
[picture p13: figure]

Fonte: (Autoria própria). Diagrama do transmissor apresentando o sinal de entrada, o sinal portador e as respectivas potências na entrada do mixer.

Tabela 6.4: Sinais de entrada e saída do circuito

Entrada | Potência (dBm) | Frequência (Mhz)
IN1 | +3 dBm | 0.1 – 800
IN2 | +17 dBm | 2600

Os cálculos foram realizados da seguinte forma:

- Sinal de entrada IN1 (IF): +3 dBm = −27dBW ~ 2 mW
- Cálculo do sinal IF:

Em dBW: IF = −27 dBW − 0,4dB + 13,3dB = −14,1 dBW Em dBm: IF = −14,1 dbW ≈ 15,9 dBm
Em watts = 0.002W ∗ 0,912 ∗ 21.38 = 0,03899W ≈ 39 mW
- Sinal de entrada IN2 (LO): 17dBm = −13 dBW ≈ 50 mW

A Figura 6.6 apresenta os sinais de entrada do circuito, passando por diferentes

estágios até as portas de entradas do mixer.

Figura 6.6 – Diagrama dos sinais na entrada do mixer

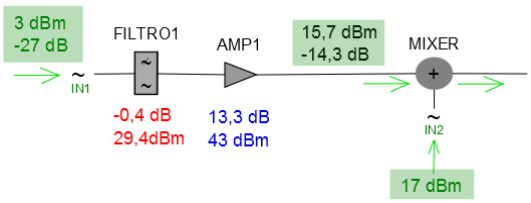
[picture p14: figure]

Fonte: (Autoria própria). Representação dos sinais nas portas de entradas do mixer, respeitando os limites do componente.

### 6.7 Análise de figura de ruído

A análise de figura de ruído é de extrema importância para a constatação da SNR

do sinal que será transmitido através da antena. A qualidade do sinal está intimamente

ligada ao valor da SNR. Além disso, pode-se verificar se a potência do sinal está

condizente com o propósito do projeto.

A Figura 6.7 apresenta um diagrama dos componentes do transmissor com seus

respectivos valores de ganho e figura de ruído em dB.

Figura 6.7: Diagrama do circuito com valores de ganho dos componentes

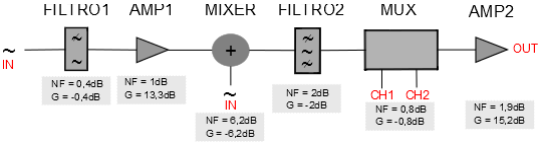
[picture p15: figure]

Fonte: (Autoria própria)

Tabela 6.5: Representação dos valores de ganhos e figura de ruído em valores lineares e em dB

| 1 | 2 | 3 | 4 | 5 | 6
| Passabaixa | AMP1 | Mixer | Passabanda | MUX | AMP2
NF (dB) | 0,4 | 1 | 6,2 | 2 | 0,8 | 1,9
NF | 1,09 | 1,26 | 4,17 | 1,58 | 1,20 | 1,55
G (dB) | -0,4 | 13,3 | -6,2 | -2 | -0,8 | 15,2
G | 0,91 | 21,38 | 0,24 | 0,63 | 0,83 | 33,11

O cálculo da figura de ruído do circuito pode ser visualizado abaixo.

NF = 1,09 +

1,26 − 1
0,91 +

4,17 − 1
0,91 ⋅ 21,38 +

1,58 − 1
0,91 ⋅ 21,38 ⋅ 0,24

+

1,2 − 1
0,91 ⋅ 21,38 ⋅ 0,24 ⋅ 0,63 +

1,55 − 1
0,91 ⋅ 21,38 ⋅ 0,24 ⋅ 0,63 ⋅ 0,83

NF = 1,09 + 0,28 + 0,16 + 0,12 + 0,07 + 0,22 = 1,92 = 2, 94dB

G = (−0,4 + 13,3 − 6,2 − 2 − 0,8 + 15,2)dB = 19, 1 dB

### 6.8 Projeto do Layout das placas de validação dos componentes

As placas de circuito impresso ou PCIs, permitem realizar a fixação e a

interligação de componentes através de trilhas de condução. O projeto do layout das

placas é determinado pelas ligações elétricas e características dos componentes e dos

sinais.

O encapsulamento dos componentes é muito importante para a fabricação das

placas. A menor largura de trilha exigida pode ser verificada, geralmente, na menor distância entre pinos dos componentes. É necessário verificar se os equipamentos que

irão realizar a prototipação e a soldagem são compatíveis com as especificações

requeridas pelos componentes e trilhas escolhidos.
É de grande importância utilizar componentes e matérias de qualidade, da mesma

forma que técnicas que visam melhorar a eficiência do circuito ou reduzir os efeitos

indesejados. O casamento de impedâncias das trilhas e o uso de vias de aterramento são

técnicas amplamente aconselhadas e fornecem um método efetivo para reduzir os efeitos

das linhas de transmissão.

Neste projeto são necessárias PCIs para testar os componentes do circuito

transmissor individualmente e para montagem do protótipo.

Para desenvolver o layout para as placas de teste dos componentes escolhidos, foi

utilizado o software Kicad, pelo fato de ser de livre distribuição, com ampla

documentação e suporte. O primeiro passo foi fazer uma busca para tentar encontrar

modelos de esquemáticos com a configuração do encapsulamento dos componentes.

Como não foram encontrados a maioria dos modelos, foi necessário cria-los. O primeiro

modelo criado foi o filtro SCLF-4.7+, que utiliza o socket YY161 da Minicircuits. A

Figura 6.8 apresenta os dados para construção do layout para o componente SCLF-4.7+

Figura 6.8 – Informações para desenvolvimento do layout das placas do Filtro 1

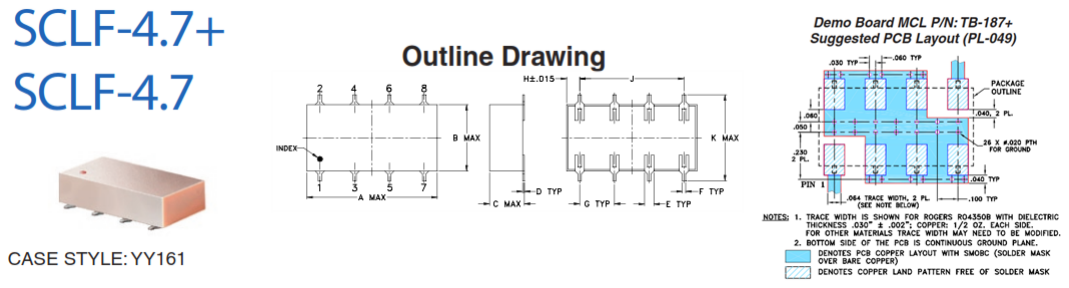
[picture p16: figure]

Fonte: (MINICIRCUITS, 2013). O componente (à esquerda), o diagrama (centro) e a sugestão de uma PCB

para teste.

6.8.1 Impedância das trilhas da PCI

O valor da impedância das trilhas da PCI estabelecido foi de 50Ω. A razão pela

qual este valor foi definido é a maior abundância de componentes com esta característica.

Para dimensionar corretamente as trilhas da PCI com esse valor de impedância,

foi necessário calcular a largura da trilha.

O conceito de CPW foi proposto em 1969 por Wen, e basicamente, propõe uma

trilha (coplanar), de largura s, separada por duas fendas de largura w, ambas com altura

h.

O dimensionamento das linhas de uma CPW pode ser feito através de uma

combinação de valores das dimensões. O cálculo da estrutura das linhas foi executado

com auxílio do software de livre distribuição Kicad, que realiza o cálculo de linhas de

micro-ondas. Deve-se analisar com cuidado os parâmetros utilizados pois a precisão requerida pelo equipamento responsável pelo design das trilhas é limitada, desta forma

exige-se a compatibilidade das dimensões calculadas. (WEN, 1969) (SIMONS, 2001)

O resultado dos layouts produzidos para os componentes selecionados do

transmissor pode ser visualizado no ANEXO B.

Figura 6.9 – Ilustração da estrutura de uma CPW

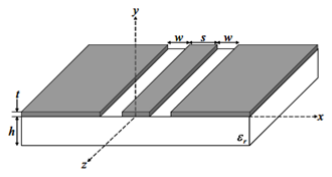
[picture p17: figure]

Fonte: (SHARMA, 1993)

6.8.2 Vias de aterramento

As vias de aterramento são fundamentais para aumentar a eficiência da

transmissão dos sinais de alta frequência em uma PCI. Trata-se de uma técnica muito

utilizada que visa equilibrar o indesejado efeito dos campos magnéticos gerados pelo

sinal.

As vias conectam os planos de terra das duas superfícies da PCI. Recomenda-se

dimensionar o espaçamento entre vias com um valor de λ/30. A Figura 6.10 ilustra as

medidas das vias de aterramento. (SEMTEC, 2006)

Figura 6.10 – Medidas das vias de aterramento

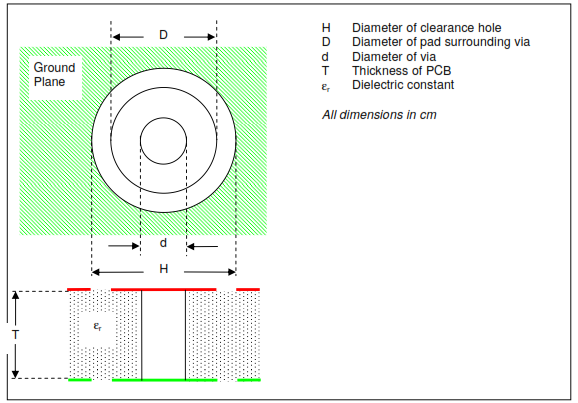
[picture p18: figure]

Fonte: (SEMTEC, 2006)

Sendo c = 300.000 m/s, o comprimento de onda do sinal de 2,26 GHz é dado por:

λ =

c
f

=

300.000.000
2.260.000.000 = 0.132m

O cálculo da distância mínima recomendada entre vias de aterramento resultou

em:

d =

λ
30 =

0.132
30 = 0.0044m = 4.4mm

### 7. CONCLUSÃO

Este trabalho propôs a construção de um protótipo de transmissor Homódino, que

opera em Banda S. Foram estudadas diferentes arquiteturas e técnicas para implementar

o circuito. A análise de figura de ruído dos componentes do sistema garante que o sinal a

ser transmitido seja corretamente dimensionado ao longo dos diferentes estágios do

transmissor. Além disso foi feita uma pesquisa e escolha de componentes reais, e

desenvolvidas placas de validação para cada um dos componentes selecionados e foram

utilizadas técnicas para minimização dos efeitos das altas frequências nas placas.

Outras implementações mais arrojadas, aprimoramentos e aplicações de novas

técnicas podem vir a utilizar as contribuições deste projeto.

As próximas etapas para dar continuidade ao projeto são:

- Simulação elétrica dos sinais e componentes de um canal do

circuito;

- Implementação e teste do canal completo em um circuito físico

real;

- Implementação de um transceptor Homódino;
- Utilização de um sistema digital para modulação, permitindo vários

esquemas remotamente configurável;

- Prototipação em FPGA de um transmissor remotamente

configurável;

ANEXO A

Este anexo apresenta as características dos componentes selecionados para

integrar o transmissor. Os dados foram retirados dos datasheets dos componentes

fornecidos pela empresa Minicircuits.

Filtro 1

Modelo: SCLF-4.7 (PASSA-BAIXA) Fcorte: 4,7 MHz
Potência de entrada: 27 dBm
0,5W (máx.)
NF: 0,4 dB

Figura A1 – Parâmetros do componente SCLF-4.7

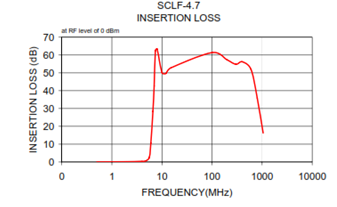
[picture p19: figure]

Fonte: (Minicircuits, 2014). Gráfico apresentando a resposta em frequência do filtro 1.

Link do Datasheet: [http://www.minicircuits.com/pdfs/SCLF-4.7.pdf]

Amplificador 1 (PA1)

Modelo: PSA4-5043+
Foperação: 0,05 – 4 GHz
Vin: 3 V(min) 5 V(típico) 6 V (máx.) Id: 58mA (típico) - 76 mA (máx.)

Pin : 17 dBm (contínuo) -
23 dBm (máx. 5 minutos)
Pout: 20,7 dBm @ 1 dB compressão
IP3: 17 dBm (máx.)
NF: 1 dB @ 2 GHz
GANHO: 13,3 dB @ 2 GHz | Potência máxima: 400
mW | Dissipação: 0,38W
(máx.)

Link do Datasheet: [http://www.minicircuits.com/pdfs/PSA4-5043+.pdf]

Mixer

Modelo: SIM-U432H+
IN1 (IF): 17 dBm (máx.) = 50 mW IN2 (LO): 17 dBm (máx.) = 50 mW
Potência máxima: 100 mW

Figura A2 – Parâmetros e ilustração do componente SIM-U432H+

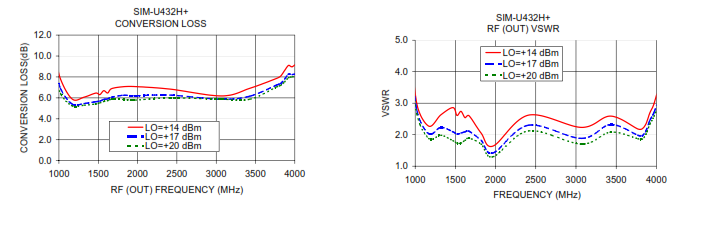
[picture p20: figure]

Fonte: (MINICIRCUITS, 2015). À esquerda o gráfico da perda de conversão pela frequência de saída e a direita a potência de saída em relação a frequência

Link do Datasheet : [http://www.minicircuits.com/pdfs/SIM-U432H+.pdf]

Filtro 2

Modelo: BFCN-2275+
Fpassagem: 2,170 – 2,380 GHz
Potência de entrada: 31,75 dBm = 1,5 W máx. NF: 0,8 dB

Figura A3 – Resposta em frequência e inserção de perdas do filtro 2

Fonte: (MINICIRCUITS, 2014)

Link do Datasheet : [http://www.minicircuits.com/pdfs/BFCN-2275+.pdf]

Multiplexador (MUX)

Modelo: VSW2-33-10W+

Foperação: 0,05 – 3 GHz

Potência do sinal de entrada: 9 W @ 2 GHz

NF: 0,8 dB máx.

Potência máxima: 100 mW

Saída RF Common: Canal 1 e canal 2 de acordo com os sinais de seleção

Sinais de seleção das entradas(canais):

Tabela A1 – Tabela representando as condições de entrada para seleção do canal de saída do multiplexador

Fonte: (MINICIRCUITS, 2014)

Link do Datasheet: [http://www.minicircuits.com/pdfs/VSW2-33-10W+.pdf]

O funcionamento do multiplexador é representado pela tabela (5) e pelas

expressões abaixo:

VCTL1

* = 5 V e VCTL2 = 0v - Seleciona o canal 1 para saída

VCTL1

* = 0 V e VCTL2 = 5v - Seleciona o canal 2 para saída

*VCTL1 (ou Control #1) = C1(layout)
**VCTL2 (ou Control#2) = C2 (layout)

Figura A4 – Funcionamento do componente MUX1

Fonte: (MINICIRCUITS, 2013)

Tabela A2 – Tabela com as informações de tensão e corrente de funcionamento do componente

Fonte: (MINICIRCUITS, 2013)

Link do Datasheet: [http://www.minicircuits.com/pdfs/VSW2-33-10W+.pdf]

Amplificador 2 (AMP2)

Modelo: PGA-105+
Foperação: 0,4 – 2,6 GHz
Vin: 3 - 5 V
Imax: 66 mA
IN : 17 dBm (contínuo) - 23 dBm (máx. 5 minutos) OUT: 19,3 dBm @ 1 dB compressão
IP3: 32,7 dBm (máx.)
NF: 1.9 dB @ 2 GHz
GANHO: 15,2 dB @ 2 GHz
Potência máxima: 400 mW
Dissipação: 0,47W (máx.)

Link do Datasheet: [http://www.minicircuits.com/pdfs/PGA-105+.pdf]

APÊNDICE A

O anexo B apresenta os layouts das placas de validação dos componentes

utilizados neste projeto desenvolvidos no software CAD de distribuição livre Kicad.

Todas as trilhas que transportam o sinal de 2,26 GHz foram dimensionadas para

realizar o casamento de impedâncias de 50 Ω.

Figura B1 – Layout do filtro 1

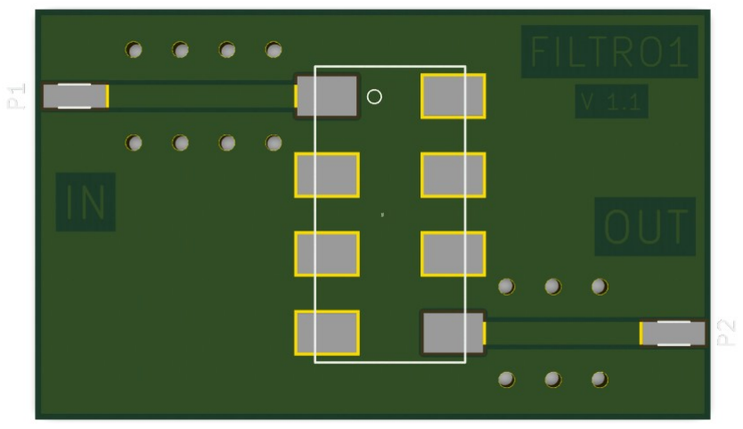
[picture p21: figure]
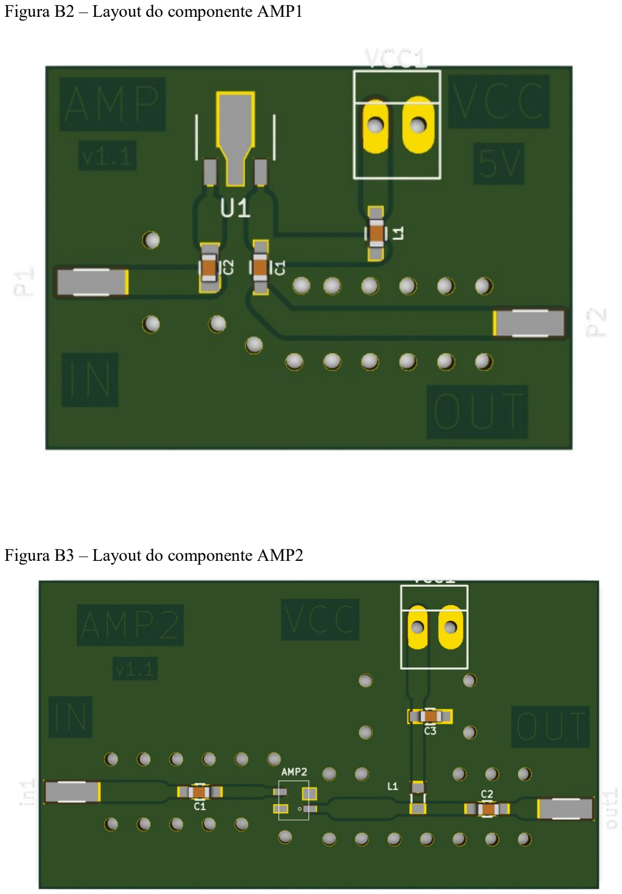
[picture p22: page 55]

Figura B2 – Layout do componente AMP1

Figura B3 – Layout do componente AMP2

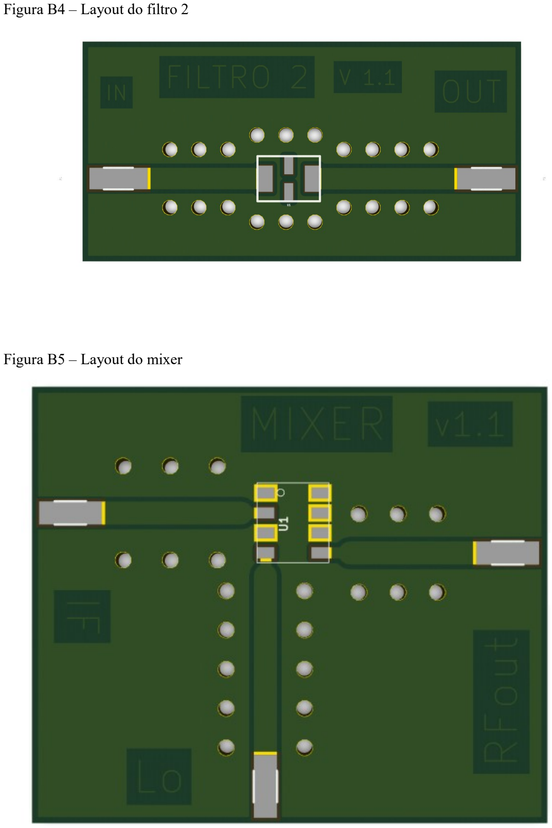
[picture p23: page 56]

Figura B4 – Layout do filtro 2

Figura B5 – Layout do mixer

Figura B6 – Layout do componente MUX

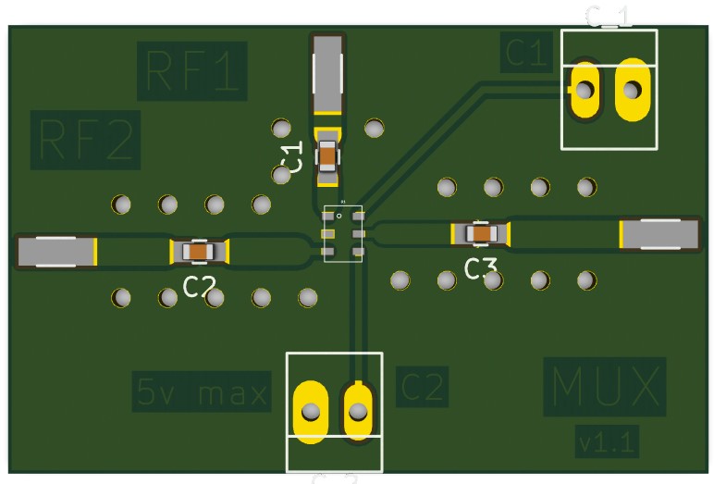
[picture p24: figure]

REFERÊNCIAS BIBLIOGRÁFICAS

BOWICK, C.; AJLUNI, C.; BLYLER, J. RF Circuit Design. 2. ed. [S.l.: s.n.], 2011.

ADDAIM; A. KHERRASA, K. Design of Low-cost Telecommunications CubeSat-class Spacecraft, Aerospace Technologies Advancements, ISBN: 978-9537619-96-1, InTech, 2010.

BENTUM, Mark. OLFAR - Orbiting Low Frequency Antenna for Radio Astronomy. TUDELFT. 2014.

HAYKIN, S. Sistemas de comunicação: Analógicos e digitais. Bookman, 2004.

LATHI, B. P. Modern Digital and Analog Communication Systems. Oxford USA Trade, 1998.

KINCHIN, A. Mathematical foundation of information theory. Dover Publications, 1957.

MURI, Paul; MCNAIR, Janise. A Survey of Communication Sub-systems for Intersatellite Linked Systems and CubeSat Missions. Journal of communications, Vol 7 Nº 4, 2012.

NASCIMENTO Juarez do, Telecomunicações. Makron Books, 1992.

POZAR, D. M. Microwave and RF Wireless Systems. 1 ed. New York, USA: [s.n.], 2001.

POZAR, D. M. Microwave Engineering. 3.ed. Hoboken, NJ, USA: J. Willey & Sons, 2005.

RAPPAPORT, T. Wireless Communications. 2nd Edition, 2011.

RAZAVI, B. RF Microelectronics. Prentice Hall, 1998.

RAZAVI, B. RF Microelectronics. 2. ed. [S.l.]: Prentice Hall, 2011.

RAZAVI, B. Design Considerations for Direct-Conversion Receivers. IEEE Transactions on Circuits and Systems, [S.l.], v.44, n.6, 1997.

SEMTECH. AN 1200.04 Application Note RF Design Guidelines: PCB Layout and Circuit Optimization, 2006.

SILVEIRA, J. Comunicação de Dados e Sistemas de Teleprocessamento. Makron, McGrawHill, 2002.

SIMONS, R. Coplanar Waveguide Circuits, Components, and Systems. John Wiley & Sons, Inc. The CubeSat Program. Cal Poly SLO CubeSat Design Specification. Rev. 13, 2014.

Stallings, W. Wireless Communications and Networks, Prentice Hall, 2002

Stallings, William. Data and Computer Communications. Prentice Hall, 6th edition, 2000.

A. K. Sharma and T. Itoh. Special Issue on Modeling and Design of Coplanar Monolithic Microwave and Millimeter-Wave Integrated Circuits. IEEE Trans. Microwave Theory Tech., Vol. 41, No. 9, Sept. 1993.

SEMTECH. RF Design Guidelines:PCB Layout and Circuit Optimization. AN 1200.04, 2006.

Tanenbaum, Andrew S. Redes de Computadores, Editora Campus, 1996.

Tucson Amateur Packet Radio Corporation. AX.25 Link Access Protocol for Amateur Packet Radio. Versão 2.2, 1998

C. P. Wen, Coplanar Waveguide: A Surface Strip Transmission Line Suitable for Nonreciprocal Gyromagnetic Device Applications. IEEE Trans. Microwave Theory Tech., Vol. 17, No. 12, pp. 1087—1090, Dec. 1969.

YAMAGUTI, W, Sistema Brasileiro de Coleta de Dados Ambientais: Estado Atual, Demandas e Estudo de Propostas de Continuidade da Missão de Coleta de Dados. INPE, 2006.

WEBSITE: | AEB | http://www.aeb.gov.br/estacoes-terrestres-ja-recebem-sinais-do-

satelite-nanosatc-br1/. (http://www.aeb.gov.br/estacoes-terrestres-ja-recebem-sinais-do-satelite-nanosatc-br1/) Acessado em 25 de maio de 2016.

WEBSITE: INPE http://www.inpe.br/crs/nanosat/NanoSatCBR1.php. Acessado em 30

de junho de 2016.

WEBSITE: AEB http://www.aeb.gov.br/falha-deixa-cubesat-nacional-inoperante/

http://www.intechopen.com/books/aerospace-technologiesadvancements/design-of-low-

cost-telecommunications-cubesat-class-spacecraft. (http://www.intechopen.com/books/aerospace-technologiesadvancements/design-of-low-cost-telecommunications-cubesat-class-spacecraft) Acessado em 30 de junho de 2016.

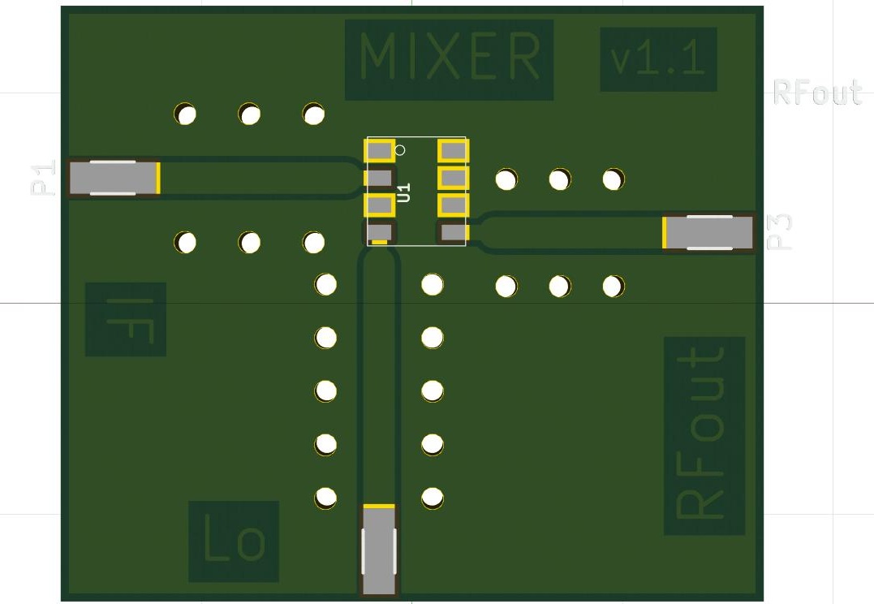
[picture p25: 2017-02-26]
3d/mixerV1.1.jpg

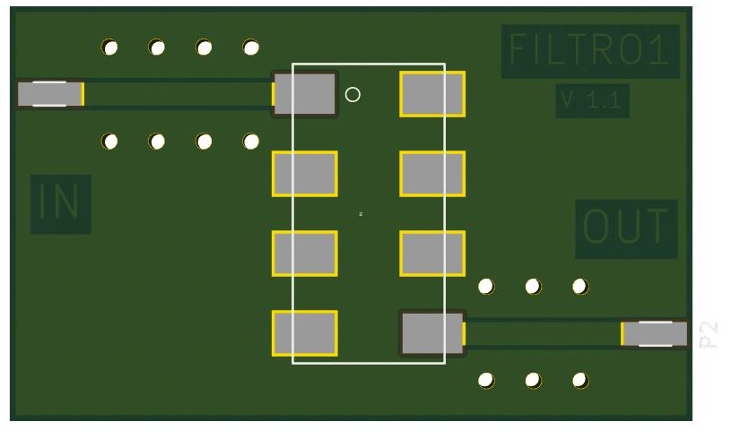
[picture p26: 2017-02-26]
3d/filtro1V1.1.jpg

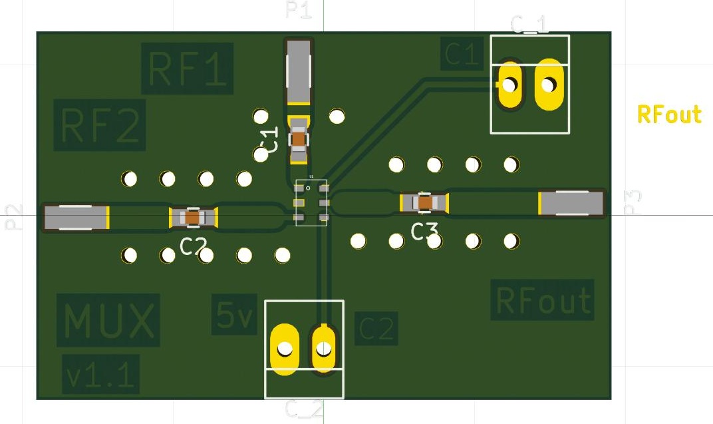
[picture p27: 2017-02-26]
3d/muxV1.1.jpg

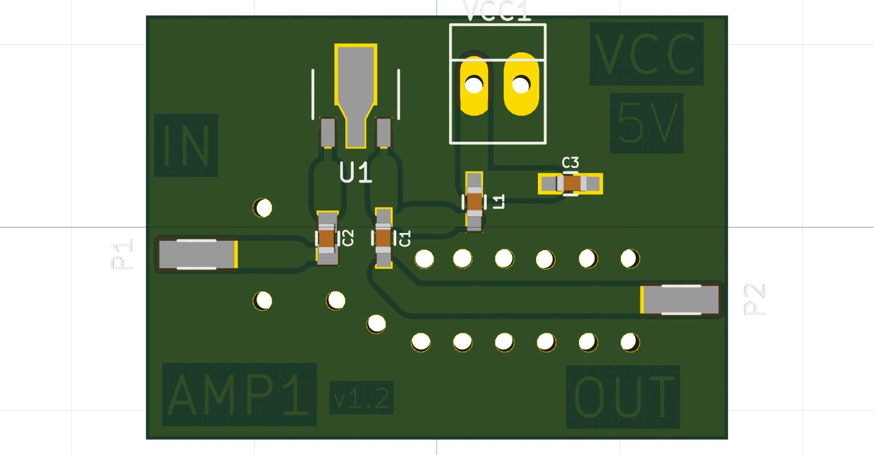
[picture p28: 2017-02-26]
3d/amp1V1.2.jpg

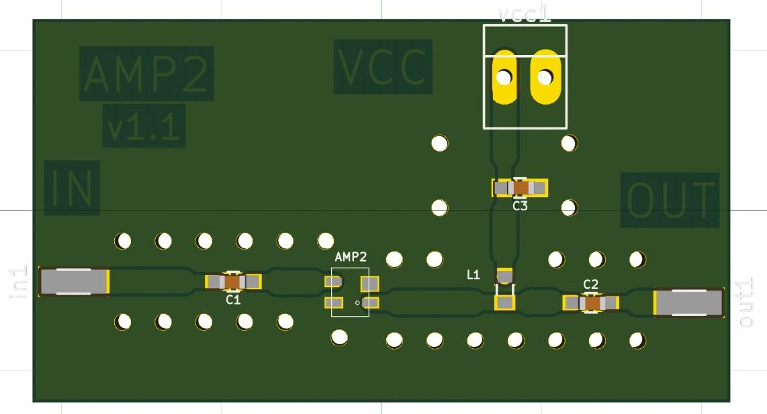
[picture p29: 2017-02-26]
3d/amp2v1.1.jpg

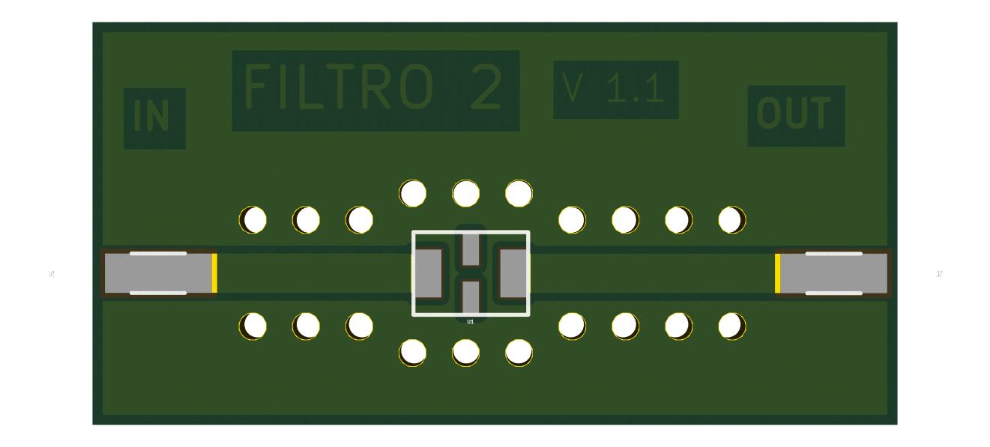
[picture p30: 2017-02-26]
3d/filtro_2v1.1.jpg
